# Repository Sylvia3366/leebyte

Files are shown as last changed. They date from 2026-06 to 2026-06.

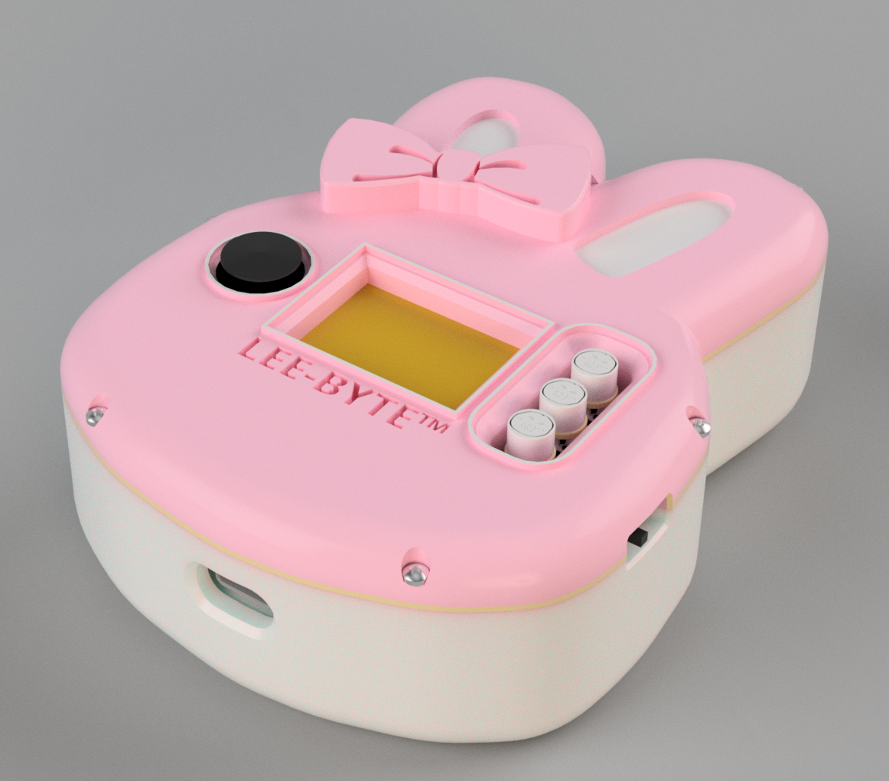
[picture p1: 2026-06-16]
images/leebyte_RENDER.png

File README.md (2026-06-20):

# LEEBYTE™
Copy of fallout_zine_template pdf-2

[ONSHAPE CAD](https://cad.onshape.com/documents/775b1919785149165ef0f27a/w/a0b05a09ec9f946b8b8a4a30/e/c002d06697f726d420ef8c8a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)
-

# What is it?
LEEBYTE is a mischevious tamagotchi pet bunny you can play with, take care of, bully, or put in your pocket and forget about for the next twenty years! It features a 2-axis joystick, three Jureumi themed buttons, and a temperature sensor that will cause LEEBYTE to have different reactions based on your enviornment :)!

# Why did I make it?
I made this project as a start point to my hardware journey! While starting with an odd, rabbit head PCB may not have been the best idea, it challenged me a lot. 

My main motivation after seeing the guide for it on Fallout website was the existing Leebit Tamagotchi [(See here!)](https://kplaceshop.com/products/stray-kids-skzoo-tamagotchi-case-set?variant=51409921999166). It's way out of my budget though, so I thought this would be the perfect chance for me to design one myself, and customize it to my own liking! Additionally, I've been wanting to get into pixel art for a while, and this project let me experiment with drawing so many different expressions and actions.

# How does it work?
LEEBYTE is unlike the usual 3-button tamagotchi pet; he can move! Using the joystick, you can take LEEBYTE on adventures and perhaps, you'll even find some cool treasures along the way... 

Like most tamagotchi, LEEBYTE also comes with 3 Jureumi themed buttons that can be pressed to feed him, play with him, or put him to sleep. Pressing two buttons at once can have some effect too :). When playing with LEEBYTE, he enjoys hula hooping, jump roping, or (if he's in the mood) you can even play a short game of some good ol' Tic-Tac-Toe. 

He's also able to detect the temperature of your enviornment. Make sure you keep him warm during the freezing winters and next to a blasting AC during the blazing summers! Otherwise, LEEBYTE might leave you...

# Designing the PCB
PCB designed on KiCad!
-
Screenshot 2026-06-15 at 11 00 14 PM
Screenshot 2026-06-15 at 11 01 25 PM
Screenshot 2026-06-15 at 11 01 33 PM
Screenshot 2026-06-14 at 1 18 59 AM

Case designed and assembled on OnShape!
-
Screenshot 2026-06-12 at 10 08 50 PM
Screenshot 2026-06-13 at 9 16 08 PM
Screenshot 2026-06-13 at 9 18 49 PM
Screenshot 2026-06-13 at 9 18 21 PM

Rendered on Fusion360!
-
Screenshot 2026-06-14 at 8 44 53 PM
leebyte_render

# Bill of Materials
| Name | Qty | Unit | Price (USD) | Total (USD) | MOQ | MOQ Price (USD) | Source |
| :--- | :---: | :---: | ---: | ---: | ---: | ---: | :--- |
| Seeed Studio XIAO ESP32 C3 | 1 | pcs | 11.14 | 11.14 | 1 | 11.14 | [Link](https://www.aliexpress.us/item/3256808047100037.html) |
| PSP 2-Axis Analog Thumb Joystick | 1 | pcs | 3.50 | 3.50 | 1 | 3.50 | [Link](https://www.adafruit.com/product/444) |
| 0.96 inch OLED Display 128x64 | 1 | pcs | 1.91 | 1.91 | 1 | 1.91 | [Link](https://www.aliexpress.us/item/2251832337475453.html) |
| Right Angle Slide Switch | 1 | pcs | 1.00 | 1.00 | 1 | 1.00 | [Link](https://www.alibaba.com/product-detail/Brand-New-Original-MST-12D18G4-SPDT_1601682630920.html) |
| 4.7k Resistor | 1 | pcs | 0.01 | 0.01 | 100 | 1.47 | [Link](https://www.aliexpress.us/item/2251832130817202.html) |
| Temperature Sensor (DS18B20) | 1 | pcs | 0.48 | 0.48 | 5 | 2.42 | [Link](https://www.aliexpress.us/item/3256808767131467.html) |
| Piezo Buzzer | 1 | pcs | 0.50 | 0.50 | 10 | 5.02 | [Link](https://www.aliexpress.us/item/3256810135642750.html) |
| Tactile Switch | 3 | pcs | 0.23 | 0.68 | 10 | 2.25 | [Link](https://www.aliexpress.us/item/3256807067168626.html) |
| M1.6 5mm Screws | 7 | pcs | 0.03 | 0.21 | 50 | 1.56 | [Link](https://www.aliexpress.us/item/2251832785290389.html) |
| M3 8mm Screws | 3 | pcs | 0.04 | 0.13 | 50 | 2.09 | [Link](https://www.aliexpress.us/item/2251832785290389.html) |
| M2 5mm Standoff | 2 | pcs | 0.15 | 0.30 | 20 | 2.94 | [Link](https://www.aliexpress.us/item/3256804631738035.html) |
| M2 Hex Nut | 2 | pcs | 0.07 | 0.14 | 50 | 3.38 | [Link](https://www.aliexpress.us/item/3256806284464354.html) |
| Battery | 1 | pcs | 5.16 | 5.16 | 1 | 5.16 | [Link](https://www.aliexpress.us/item/3256808658204287.html) |
| PCB | 1 | pcs | 0.40 | 0.40 | 5 | 2.00 | [Link](https://jlcpcb.com) |
| PLA 3D Printed Case | 1 | pcs | - | - | - | - | - |
| **Total** | **27** | **-** | **-** | **25.56** | **-** | **45.84** | **-** |

# Build & Assembly
Required Tools
-
1. Solder
2. Soldering iron
3. Tweezers
4. Screwdriver for M3/M2/M1.6 screws
5. Computer w. a USB port
6. 3D printer

Assembly
-
1. Solder all parts onto the PCB.
2. Secure the button caps onto the tact switches.
3. Secure the joystick with 2 M2 5mm screws, M2 standoffs, and M2 hex nuts.
4. Place the battery in the open part below the bottom case.
5. Place PCB into the bottom case and wire to battery.
6. Secure the PCB with 3 M3 screws.
7. Place the top case over the bottom and secure with the M1.6 screws.
8. Use Arduino IDE for the firmware.
9. Connect the ESP32 to your computer via USB-C to upload code.
10. Upload firmware.
11. Test the OLED display and test the joystick inputs.

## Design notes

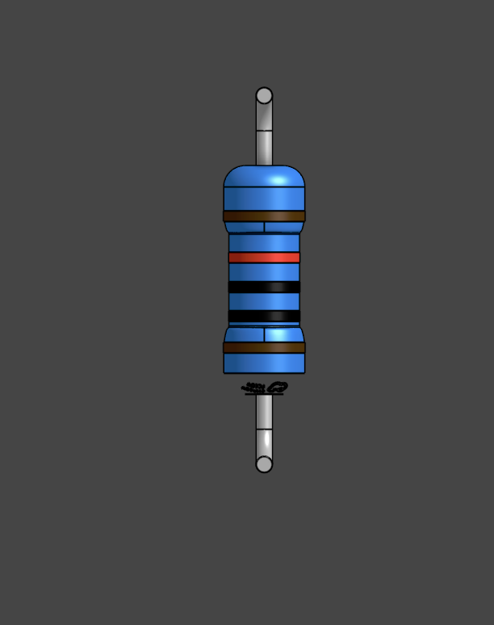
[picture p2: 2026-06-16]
case/CAD/4.7k Resistor Model/Resistor.png

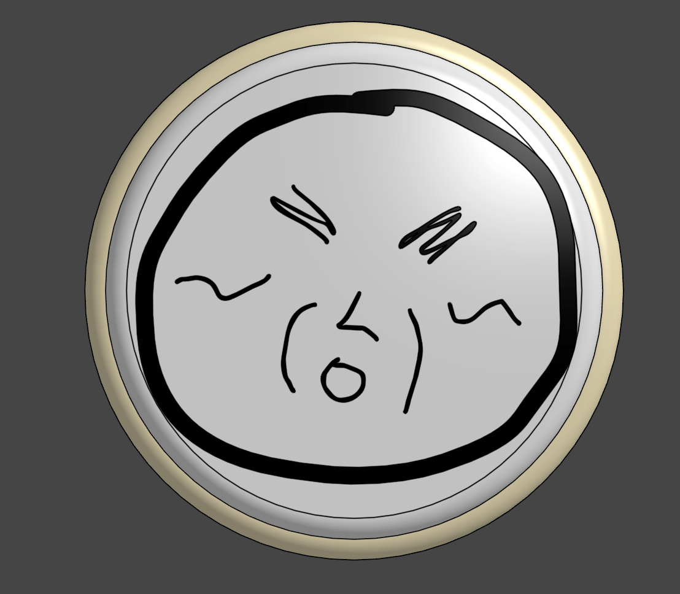
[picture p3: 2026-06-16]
case/Button Cap Model/Button.png

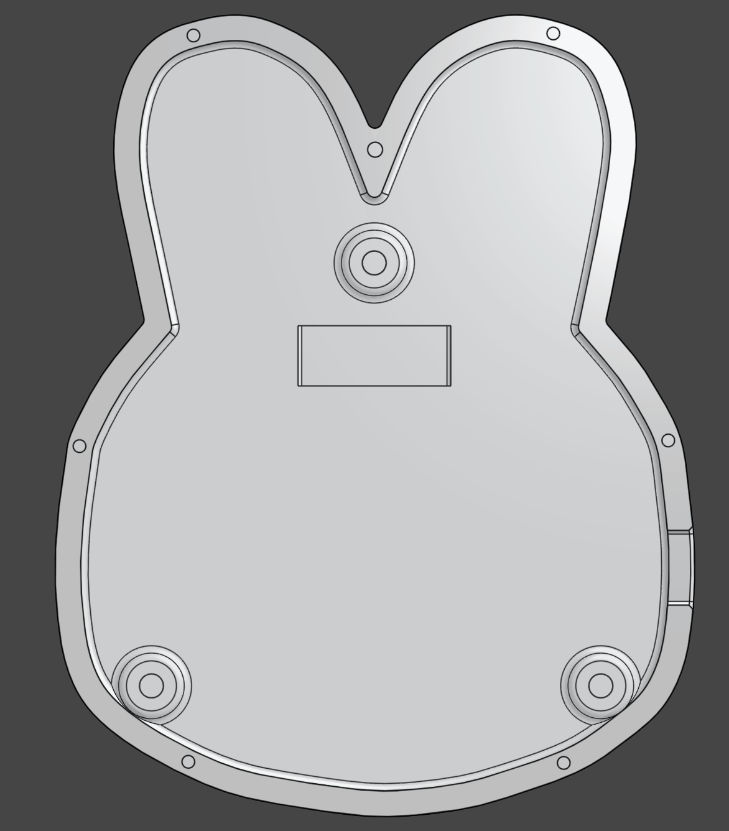
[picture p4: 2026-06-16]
case/Bottom Case Model/Btm_case.png

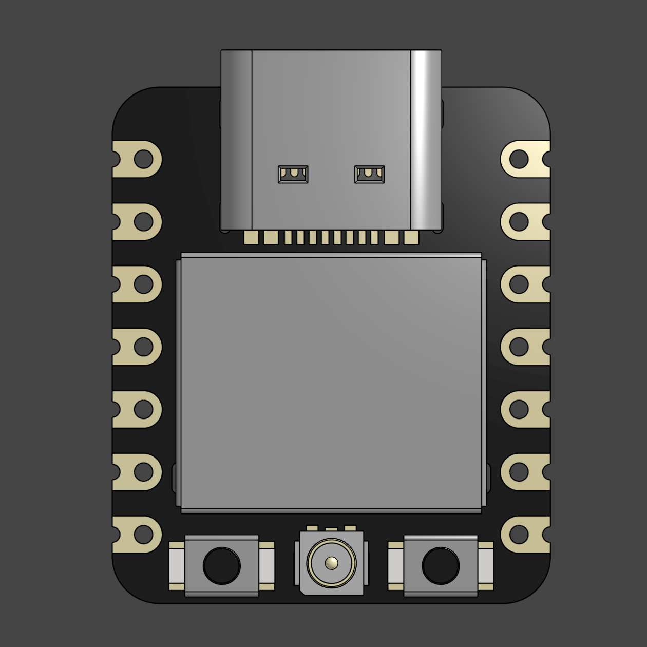
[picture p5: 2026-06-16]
case/CAD/Seeed Studio XIAO ESP32 C3 Model/seeed1.png

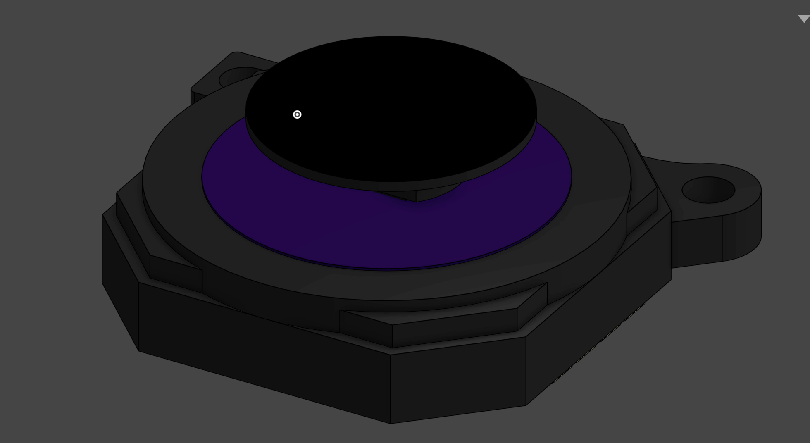
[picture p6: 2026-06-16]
case/CAD/2-axis Analog Thumb Joystick Model/Joystick.png

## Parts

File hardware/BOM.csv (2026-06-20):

Name | Qty | Unit | Price (USD) | Total (USD) | MOQ | MOQ Price (USD) | Source
Seeed Studio XIAO ESP32 C3 | 1 | pcs | 11.14 | 11.14 | 1 | 11.14 | https://www.aliexpress.us/item/3256808047100037.html
PSP 2-Axis Analog Thumb Joystick | 1 | pcs | 3.50 | 3.50 | 1 | 3.50 | https://www.adafruit.com/product/444
0.96 inch OLED Display 128x64 | 1 | pcs | 1.91 | 1.91 | 1 | 1.91 | https://www.aliexpress.us/item/2251832337475453.html
Right Angle Slide Switch | 1 | pcs | 1.00 | 1.00 | 1 | 1.00 | https://www.alibaba.com/product-detail/Brand-New-Original-MST-12D18G4-SPDT_1601682630920.html
4.7k Resistor | 1 | pcs | 0.01 | 0.01 | 100 | 1.47 | https://www.aliexpress.us/item/2251832130817202.html
Temperature Sensor (DS18B20) | 1 | pcs | 0.48 | 0.48 | 5 | 2.42 | https://www.aliexpress.us/item/3256808767131467.html
Piezo Buzzer | 1 | pcs | 0.50 | 0.50 | 10 | 5.02 | https://www.aliexpress.us/item/3256810135642750.html
Tactile Switch | 3 | pcs | 0.23 | 0.68 | 10 | 2.25 | https://www.aliexpress.us/item/3256807067168626.html
M1.6 5mm Screws | 7 | pcs | 0.03 | 0.21 | 50 | 1.56 | https://www.aliexpress.us/item/2251832785290389.html
M3 8mm Screws | 3 | pcs | 0.04 | 0.13 | 50 | 2.09 | https://www.aliexpress.us/item/2251832785290389.html
M2 5mm Standoff | 2 | pcs | 0.15 | 0.30 | 20 | 2.94 | https://www.aliexpress.us/item/3256804631738035.html
M2 Hex Nut | 2 | pcs | 0.07 | 0.14 | 50 | 3.38 | https://www.aliexpress.us/item/3256806284464354.html
Battery | 1 | pcs | 5.16 | 5.16 | 1 | 5.16 | https://www.aliexpress.us/item/3256808658204287.html
PLA 3D Printed Case | 1 | pcs | - | - | - | - | -
PCB | 1 | pcs | 0.40 | 0.40 | 5 | 2.00 | https://jlcpcb.com
Total | 27 | - | - | 25.56 | - | 45.84 | -

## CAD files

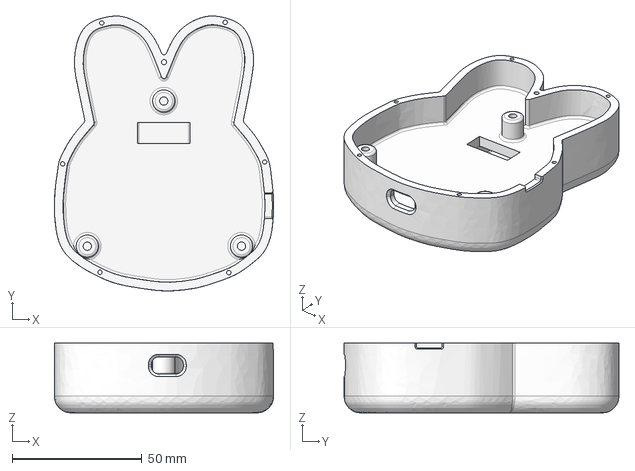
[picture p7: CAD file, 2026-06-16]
case/Bottom Case Model/Bottom_case.step
84.7 x 106.1 x 27.0 mm

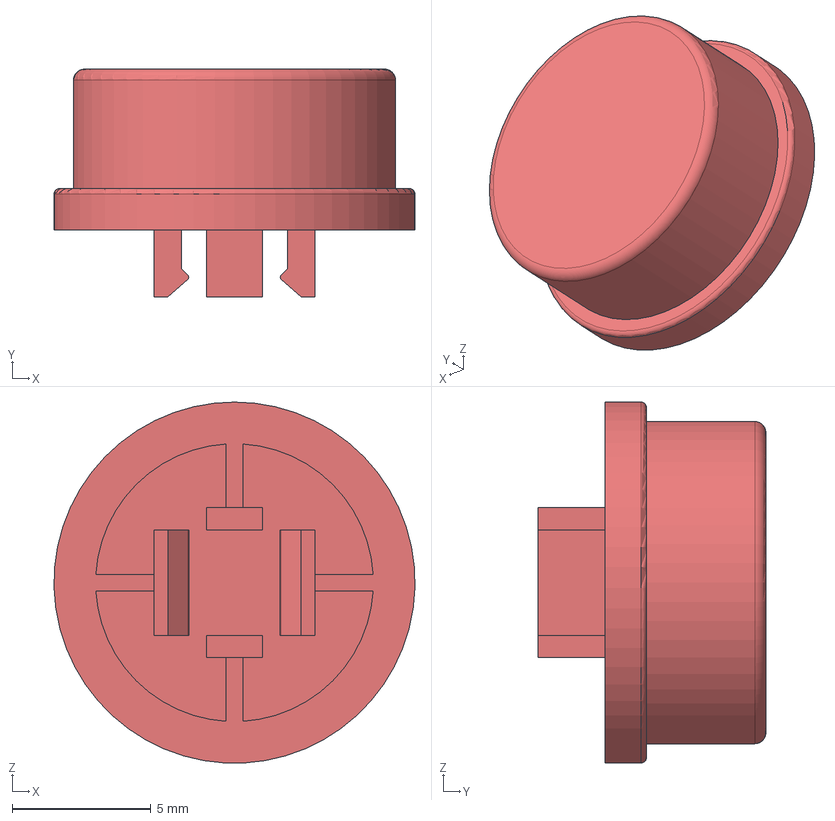
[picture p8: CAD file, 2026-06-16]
case/Button Cap Model/12mm Push Button Cap (REFERENCE).step
13.0 x 8.20 x 13.0 mm

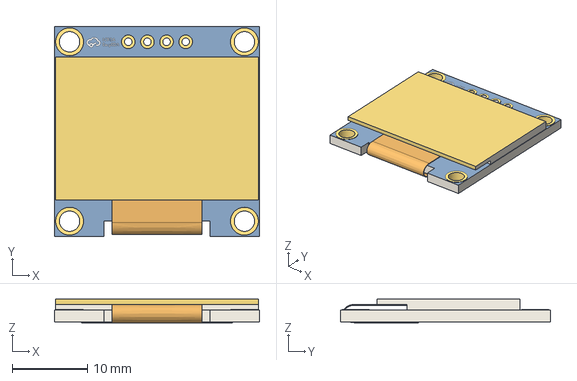
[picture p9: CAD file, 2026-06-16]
case/CAD/128x64 OLED Model/OLED-TH_L27.8-W27.2-P2.54_C9900033791 (1).step
27.2 x 27.8 x 3.12 mm

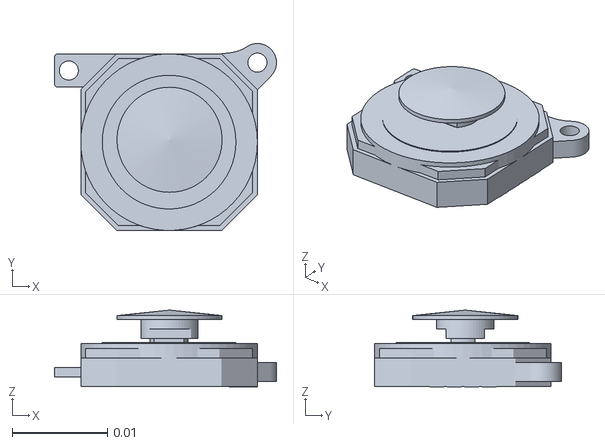
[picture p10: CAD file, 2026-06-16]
case/CAD/2-axis Analog Thumb Joystick Model/PspJoystick v5.stl
0.0232 x 0.0196 x 0.00805

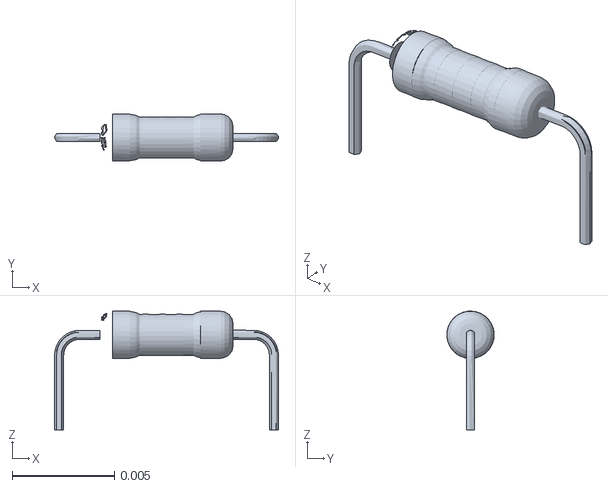
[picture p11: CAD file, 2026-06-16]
case/CAD/4.7k Resistor Model/RES-TH_D2.3-L6.5-P10.50 (2).stl
0.0109 x 0.00232 x 0.00581

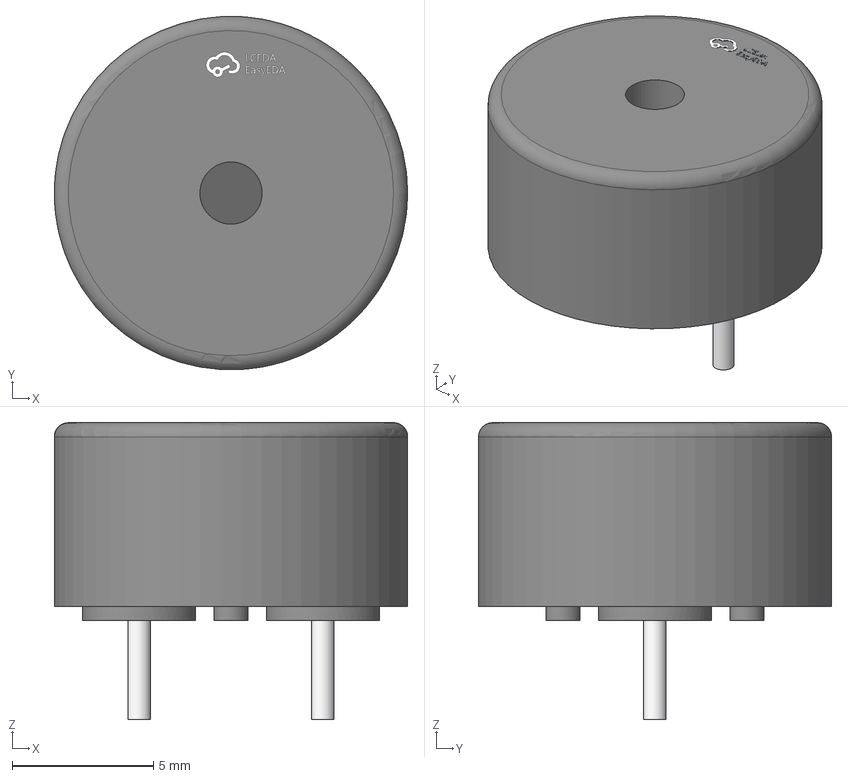
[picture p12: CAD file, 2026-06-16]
case/CAD/Buzzer Model/BUZ-TH_BD12.5-H7.0-P6.5 (1).step
12.5 x 12.5 x 10.5 mm

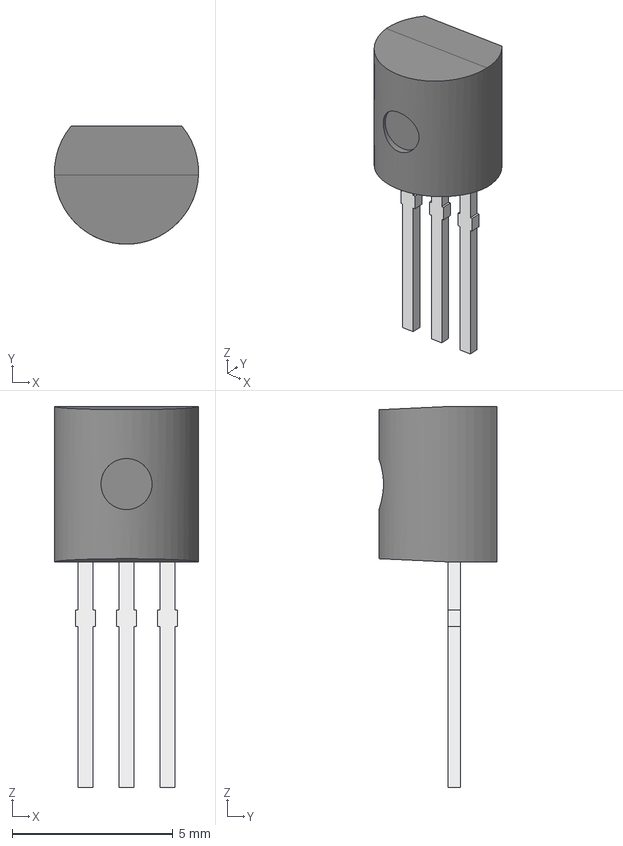
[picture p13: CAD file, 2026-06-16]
case/CAD/DS18B20 Model/Áã¼þ11 (1).step
4.48 x 3.68 x 11.8 mm

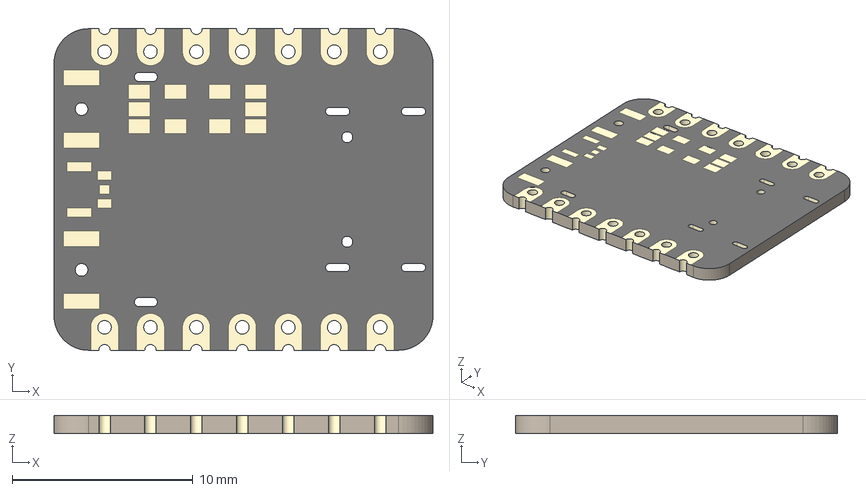
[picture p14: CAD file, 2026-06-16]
case/CAD/Seeed Studio XIAO ESP32 C3 Model/Seeed Studio XIAO-ESP32-C3 - Seeed Studio XIAO-ESP32-C3 v15.step
21.0 x 17.8 x 1 mm

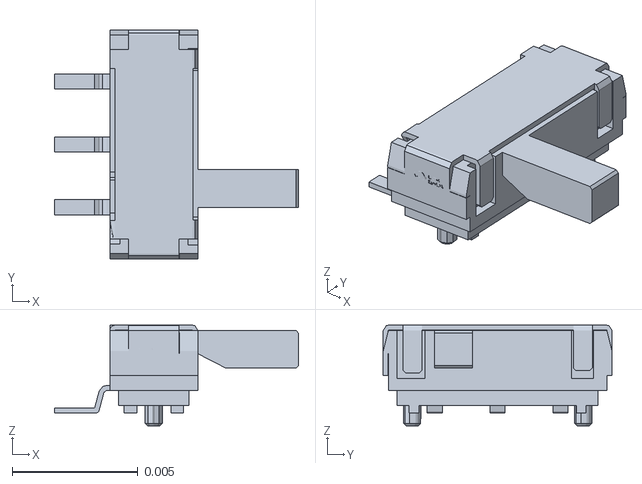
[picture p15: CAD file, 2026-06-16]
case/CAD/Slide Switch Model/tamagotchipcb123 1.stl
0.0097 x 0.00911 x 0.004

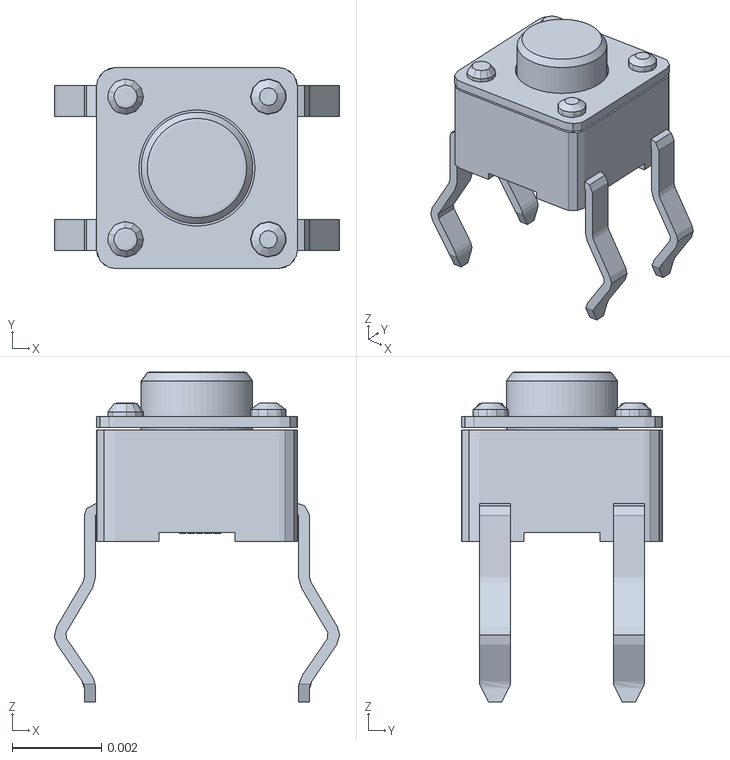
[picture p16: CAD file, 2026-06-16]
case/CAD/Tact Switch Model/SW-TH_4P-L4.5-W4.5-P3.00-LS4.8.stl
0.0064 x 0.0045 x 0.0074

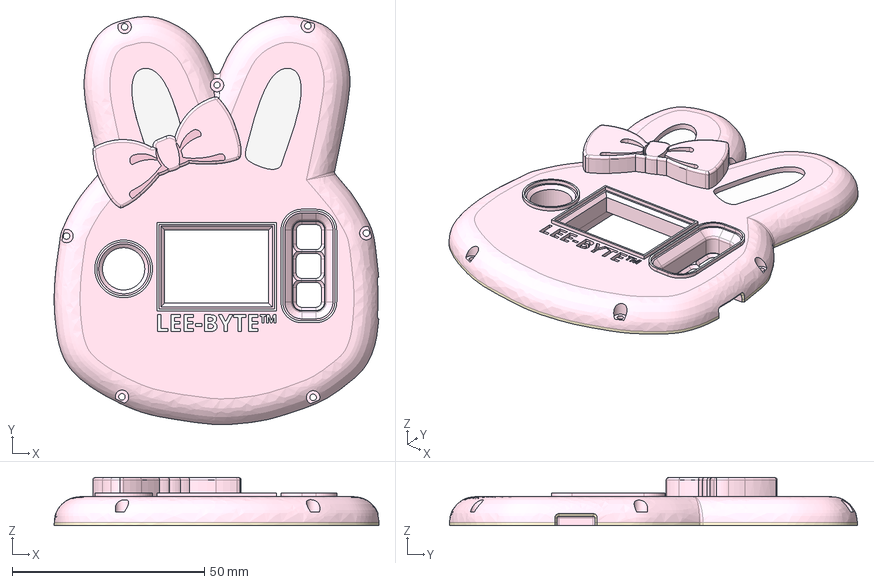
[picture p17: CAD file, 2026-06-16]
case/Top Case Model/Top_case.step
84.4 x 106.1 x 12.5 mm

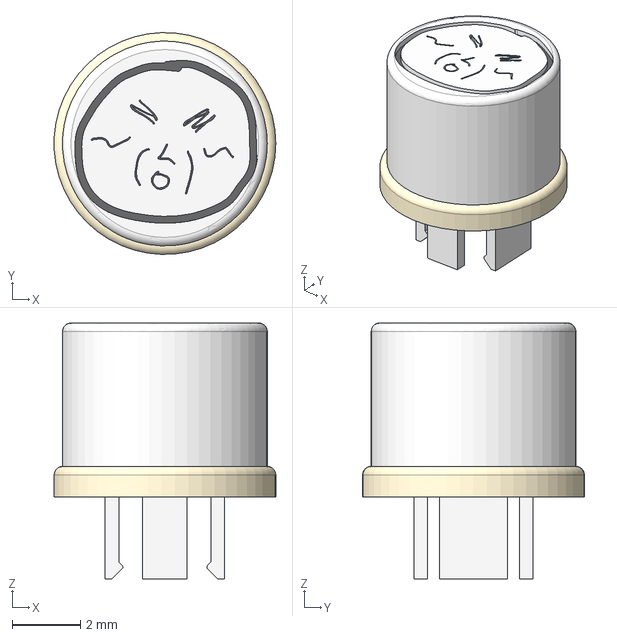
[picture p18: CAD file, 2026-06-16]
case/Button Cap Model/Button_cap.step
6.49 x 6.50 x 7.50 mm

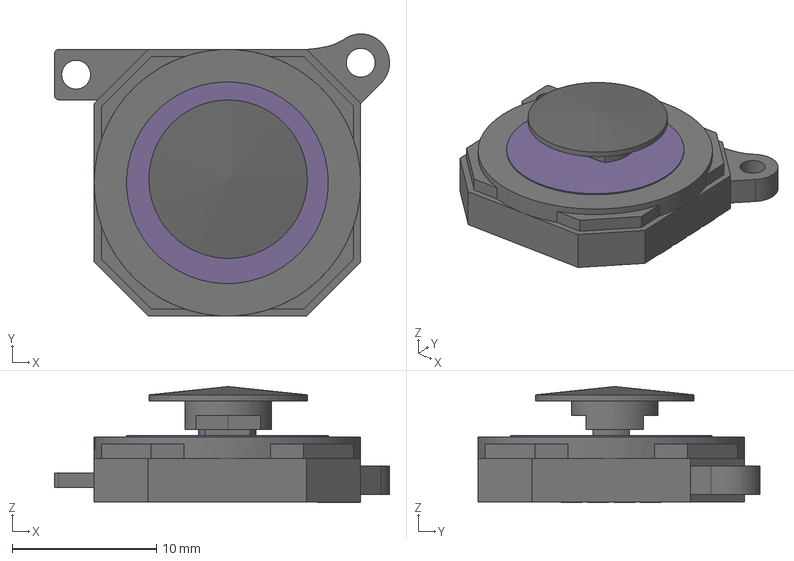
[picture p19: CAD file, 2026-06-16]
case/CAD/2-axis Analog Thumb Joystick Model/PspJoystick v5-2.step
23.2 x 19.6 x 8.05 mm
PspJoystick v6 x 7

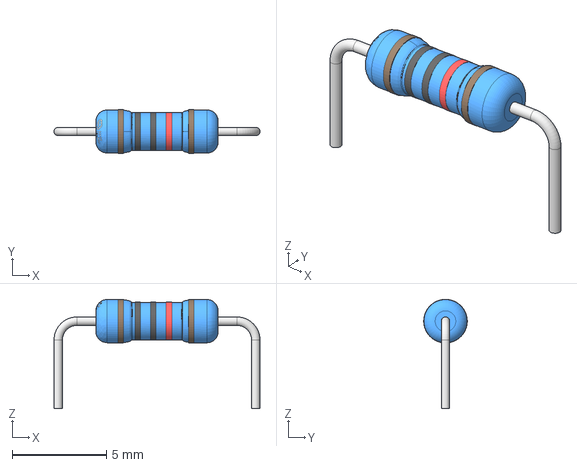
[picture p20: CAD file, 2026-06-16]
case/CAD/4.7k Resistor Model/RES-TH_D2.3-L6.5-P10.50 (1).step
10.9 x 2.32 x 5.81 mm

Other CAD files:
case/CAD/Slide Switch Model/Slide Switch.step
case/CAD/Tact Switch Model/SW-TH_4P-L4.5-W4.5-P3.00-LS4.8 (1).step
case/CAD/M1.6x0.35mm 6mm Screw Model/PZ Pan head screw M1.6x0.35 x 6.stl
case/CAD/M2 4mm Standoff Model/M2 x 5 across flats 4mm.step
case/Bottom Case Model/Bottom_case.stl
case/Button Cap Model/12mm Push Button Cap (REFERENCE).stl
case/Button Cap Model/Button_cap.stl
case/CAD/128x64 OLED Model/OLED-TH_L27.8-W27.2-P2.54_C9900033791 (1).stl
case/CAD/Buzzer Model/BUZ-TH_BD12.5-H7.0-P6.5 (1).stl
case/CAD/DS18B20 Model/Áã¼þ11 (1).stl
case/CAD/M1.6x0.35mm 6mm Screw Model/tamagotchipcb123 1 - PZ Pan head screw M1.6x0.35 x 8.step
case/CAD/M2 4mm Standoff Model/M2 x 5 across flats 4mm.stl
case/CAD/M2 Hexnut Model/Hex nut style 1 grade A & B M2x0.4.step
case/CAD/M2 Hexnut Model/Hex nut style 1 grade A & B M2x0.4.stl
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

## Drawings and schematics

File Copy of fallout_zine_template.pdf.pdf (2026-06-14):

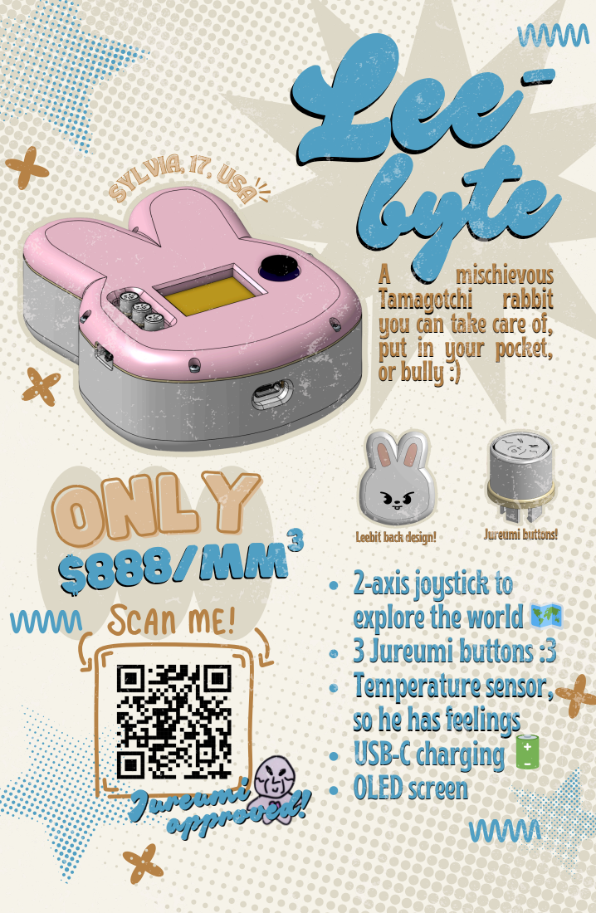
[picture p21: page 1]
Lee- byte; onlyy $888/mm; 2-axis joystickto; OLED screen; SYLVIA, 17, USA; Leebitbackdesign!; Jureumibuttons!

A mischievous
Tamagotchi rabbit
you can take care of,
put in your pocket,
orbully:)

2-axis joystickto
explore the world️
explore the world🗺
3 Jureumibuttons :3
Temperature sensor,
so he has feelings
USB-C charging🔋
OLED screen

Jureumi Jureumi Jureumi

approved! approved! approved!

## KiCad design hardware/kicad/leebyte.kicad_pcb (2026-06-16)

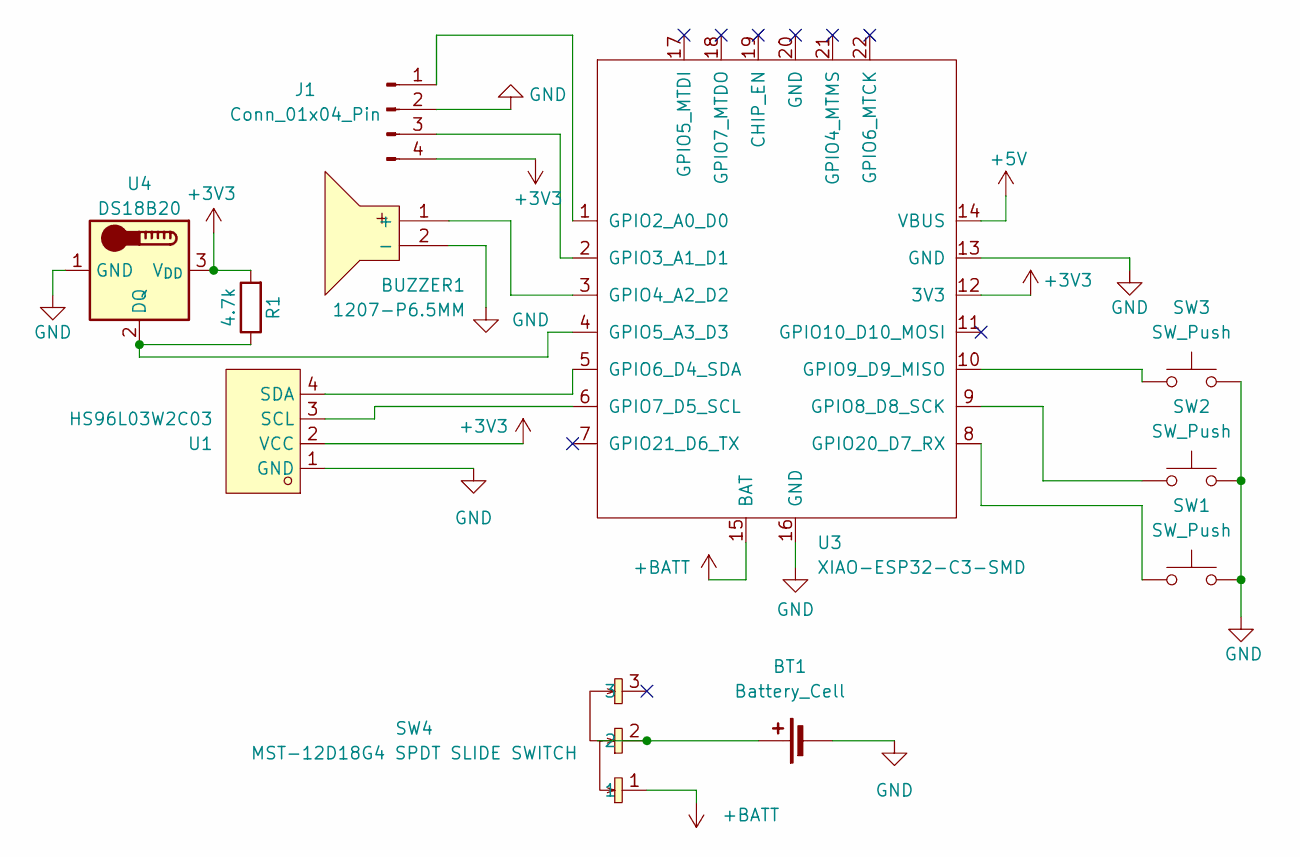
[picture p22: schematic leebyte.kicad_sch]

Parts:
BT1: Battery_Cell; PinHeader_1x02_P2.54mm_Vertical
BUZZER1: 1207-P6.5MM; BUZ-TH_BD12.5-P6.50-D1.4; MPN 1207-P6.5MM; LCSC Part C49246964
J1: Conn_01x04_Pin; JOYSTICK-PSP1000
R1: 4.7k; RES-TH_BD2.3-L6.5-P10.50-D0.5
SW1, SW2, SW3: SW_Push; SW-TH_4P-L4.5-W4.5-P3.00-LS4.8
SW4: MST-12D18G4 SPDT SLIDE SWITCH; SW-SMD_MST-12D18G4-SPDT-SLIDE-SWITCH; MPN MST-12D18G4 SPDT Slide Switch; LCSC Part C49023767
U1: HS96L03W2C03; OLED-TH_L27.8-W27.2-P2.54_C9900033791; MPN HS96L03W2C03; LCSC Part C5248080
U3: XIAO-ESP32-C3-SMD; XIAO-ESP32-C3-DIP-SMD
U4: DS18B20; TO-92-3_L4.9-W3.7-P1.27-L

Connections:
+3V3: J1.4, R1.2, U1.2 (VCC), U3.12 (3V3), U4.3 (V_{DD})
+5V: U3.14 (VBUS)
+BATT: SW4.1, U3.15 (BAT)
GND: BT1.2 (-), BUZZER1.2 (-), J1.2, SW1.2, SW2.2, SW3.2, U1.1 (GND), U3.13 (GND), U3.16 (GND), U4.1 (GND)
unnamed: BT1.1 (+), SW4.2
unnamed: BUZZER1.1 (+), U3.3 (GPIO4_A2_D2)
unnamed: J1.1, U3.1 (GPIO2_A0_D0)
unnamed: J1.3, U3.2 (GPIO3_A1_D1)
unnamed: U1.3 (SCL), U3.6 (GPIO7_D5_SCL)
unnamed: U1.4 (SDA), U3.5 (GPIO6_D4_SDA)
unnamed: R1.1, U3.4 (GPIO5_A3_D3), U4.2 (DQ)
unnamed: SW2.1, U3.9 (GPIO8_D8_SCK)
unnamed: SW3.1, U3.10 (GPIO9_D9_MISO)
unnamed: SW1.1, U3.8 (GPIO20_D7_RX)

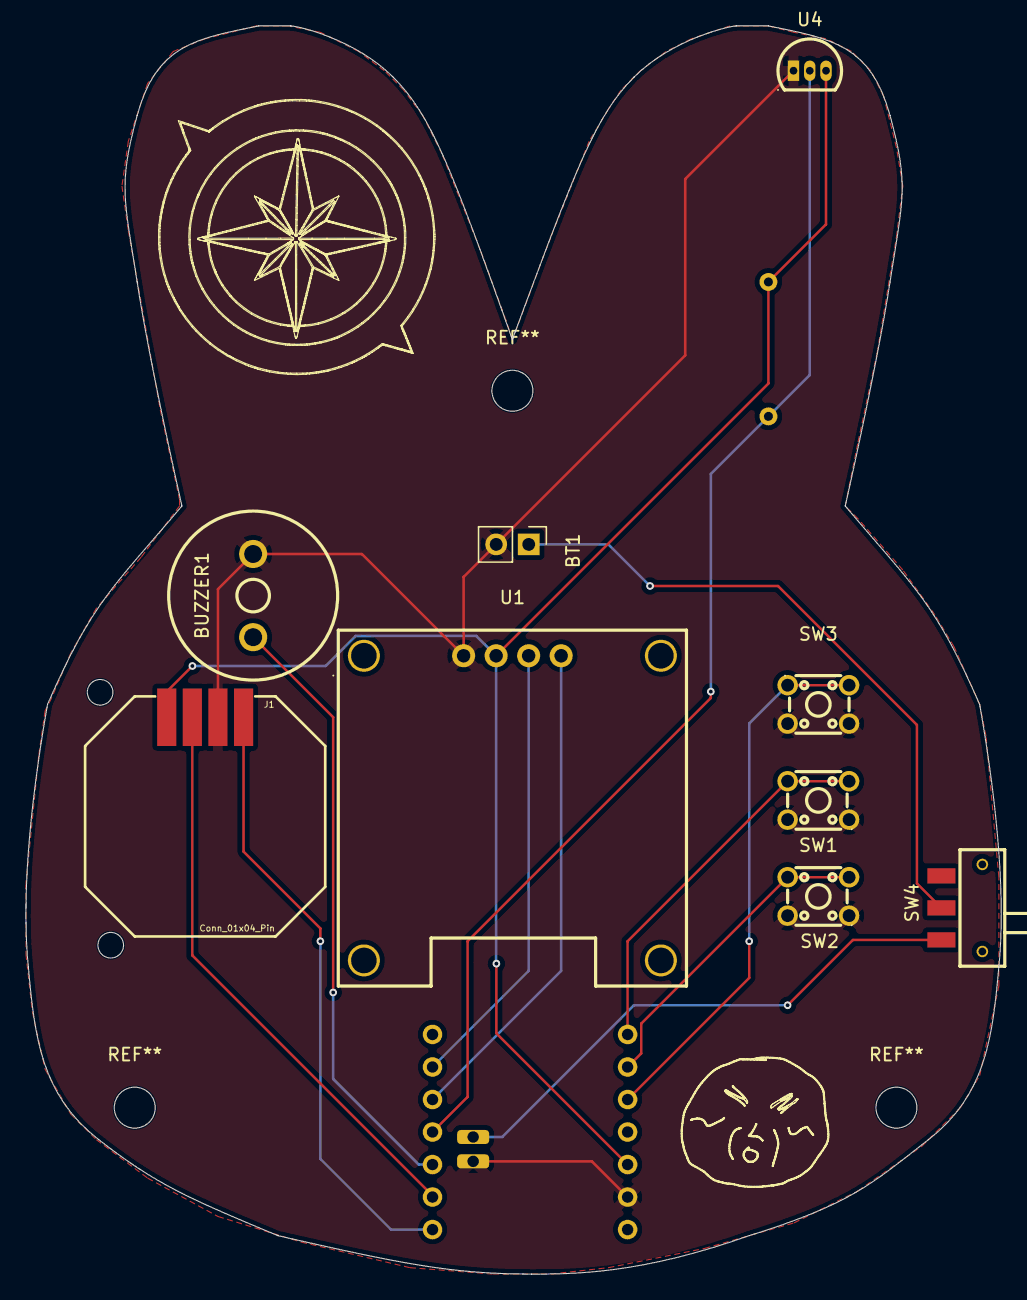
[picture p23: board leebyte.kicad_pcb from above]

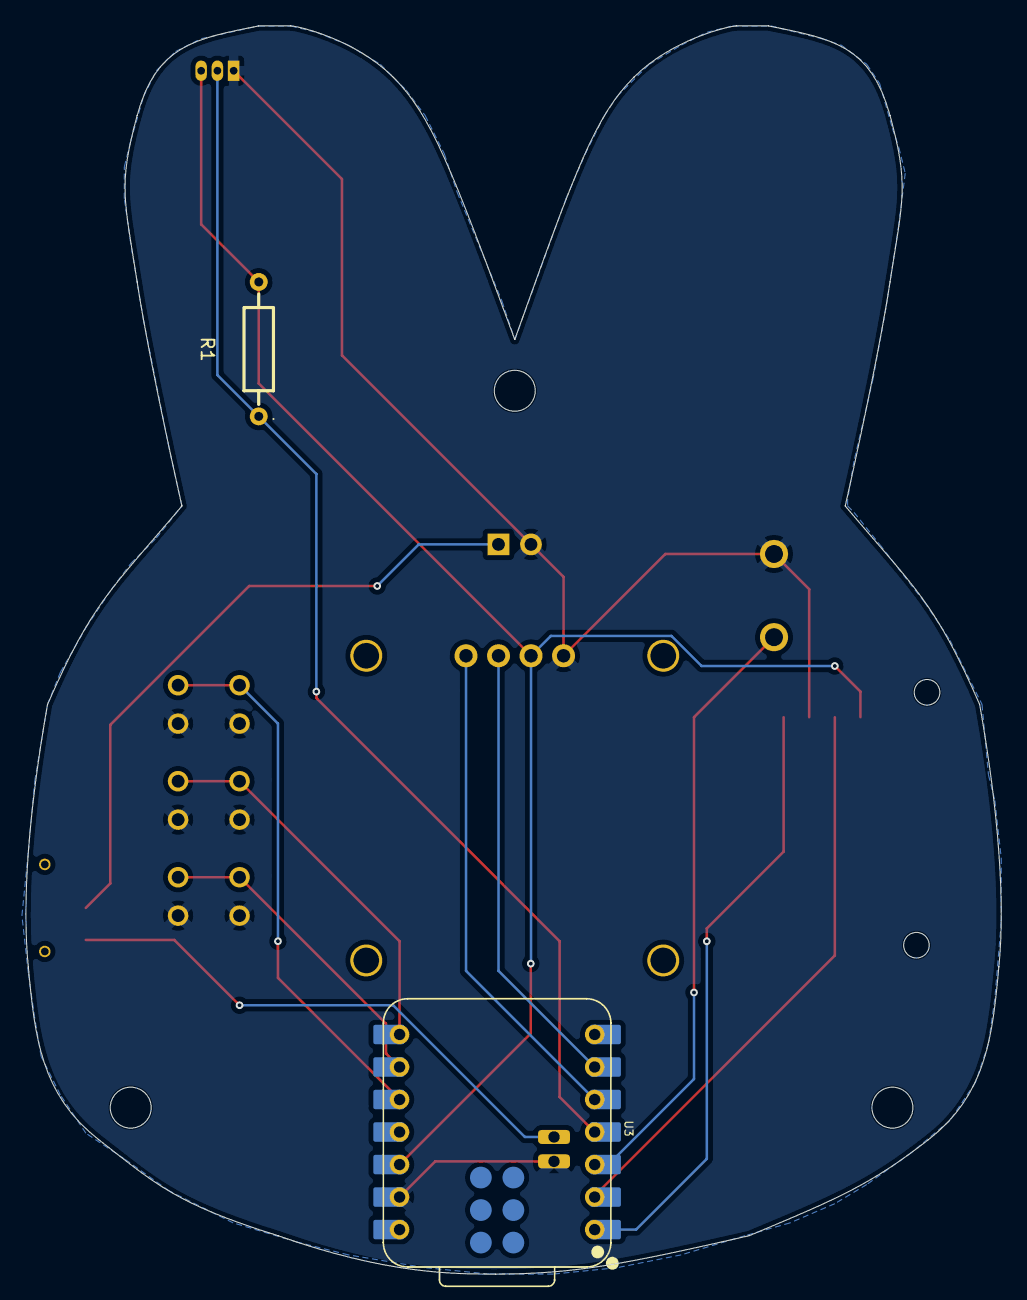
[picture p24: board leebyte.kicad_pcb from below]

Board: 2 copper layers, 76.2 x 97.5 mm, 11 parts (2 on the bottom side), 13 nets.

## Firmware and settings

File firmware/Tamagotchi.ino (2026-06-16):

//------------LIBS------------
#include <Wire.h>
#include <Adafruit_GFX.h>
#include <Adafruit_SSD1306.h>
#include <OneWire.h>
#include <DallasTemperature.h>

//------------DEFINE GIPO------------
#define BTN1 20
#define BTN2 8
#define BTN3 9
#define SDA_PIN 6
#define SCL_PIN 7
#define BUZZER 4
#define TEMP 5
#define LEFT_RIGHT 2
#define UP_DOWN 3

//------------CONFIGURE HARDWARE------------
#define SCREEN_WIDTH 128
#define SCREEN_HEIGHT 64
#define OLED_RESET -1
Adafruit_SSD1306 display(SCREEN_WIDTH, SCREEN_HEIGHT, &Wire, OLED_RESET);

#define TEMP_PIN D3
OneWire oneWire(TEMP_PIN);
DallasTemperature sensors(&oneWire);

#define BTN_TOP D9
#define BTN_MIDDLE D8
#define BTN_BOTTOM D7

#define BUZZER_PIN D2

#define X_PIN D0
#define Y_PIN D1

//------------CREATE PET------------
struct Pet {
  int hunger;
  int happiness;
  int energy;
  unsigned long age;
};

Pet pet;

//------------PET ANIMATIONS------------
const unsigned char PROGMEM petNeutral[] = {
  0b00000000, 0b00000000, 0b00000000, 0b00000000,
  0b00000000, 0b11100000, 0b00000111, 0b00000000,
  0b00000001, 0b00010000, 0b00001000, 0b10000000,
  0b00000010, 0b00010000, 0b00001000, 0b01000000,
  0b00000100, 0b11001000, 0b00010011, 0b00100000,
  0b00000100, 0b11001000, 0b00010011, 0b00100000,
  0b00000100, 0b11100100, 0b00100111, 0b00100000,
  0b00000010, 0b01110010, 0b01001110, 0b01000000,
  0b00000001, 0b01111010, 0b01011110, 0b10000000,
  0b00000001, 0b00011001, 0b10011000, 0b10000000,
  0b00000010, 0b00000000, 0b00000000, 0b01000000,
  0b00000100, 0b00000000, 0b00000000, 0b00100000,
  0b00000100, 0b00000000, 0b00000000, 0b00100000,
  0b00000100, 0b00011000, 0b00011000, 0b00100000,
  0b00001000, 0b00011000, 0b00011000, 0b00010000,
  0b00001000, 0b00011000, 0b00011000, 0b00010000,
  0b00001000, 0b00000001, 0b10000000, 0b00010000,
  0b00001000, 0b00000000, 0b00000000, 0b00010000,
  0b00001000, 0b00000000, 0b00000000, 0b00010000,
  0b00001000, 0b00001111, 0b11110000, 0b00010000,
  0b00000100, 0b00000010, 0b01000000, 0b00100000,
  0b00000100, 0b00000011, 0b11000000, 0b00100000,
  0b00000011, 0b00000000, 0b00000000, 0b11000000,
  0b00000010, 0b00000000, 0b00000000, 0b01000000,
  0b00000100, 0b00000000, 0b00000000, 0b00100000,
  0b00000100, 0b01000000, 0b00000010, 0b00100000,
  0b00000010, 0b01000000, 0b00000010, 0b01000000,
  0b00000001, 0b11000000, 0b00000011, 0b10000000,
  0b00000000, 0b01000000, 0b00000010, 0b00000000,
  0b00000000, 0b01000000, 0b00000010, 0b00000000,
  0b00000000, 0b01000001, 0b10000010, 0b00000000,
  0b00000000, 0b00111110, 0b01111100, 0b00000000
};
const unsigned char PROGMEM petHappy[] = {
  0b00000000, 0b00000000, 0b00000000, 0b00000000,
  0b00000000, 0b11100000, 0b00000111, 0b00000000,
  0b00000001, 0b00010000, 0b00001000, 0b10000000,
  0b00000010, 0b00010000, 0b00001000, 0b01000000,
  0b00000100, 0b11001000, 0b00010011, 0b00100000,
  0b00000100, 0b11001000, 0b00010011, 0b00100000,
  0b00000100, 0b11100100, 0b00100111, 0b00100000,
  0b00000010, 0b01110010, 0b01001110, 0b01001010,
  0b00000001, 0b01111010, 0b01011110, 0b10011111,
  0b01010001, 0b00011001, 0b10011000, 0b10001110,
  0b01110010, 0b00000000, 0b00000000, 0b01000100,
  0b00100100, 0b00000000, 0b00000000, 0b00100000,
  0b00000100, 0b00000000, 0b00000000, 0b00100000,
  0b00000100, 0b00110000, 0b00001100, 0b00100000,
  0b00001000, 0b00001000, 0b00010000, 0b00010000,
  0b00001000, 0b00000100, 0b00100000, 0b00010000,
  0b00001000, 0b00111001, 0b10011100, 0b00010000,
  0b00001000, 0b00000000, 0b00000000, 0b00010000,
  0b00001001, 0b10001001, 0b10010001, 0b10010000,
  0b00001001, 0b10000110, 0b01100001, 0b10010000,
  0b00000100, 0b00000100, 0b00100000, 0b00100000,
  0b00000100, 0b00000010, 0b01000000, 0b00100000,
  0b00000011, 0b00000001, 0b10000000, 0b11000000,
  0b00000010, 0b00000000, 0b00000000, 0b01000000,
  0b00000100, 0b00000000, 0b00000000, 0b00100000,
  0b00000100, 0b01000000, 0b00000010, 0b00100000,
  0b00000010, 0b01000000, 0b00000010, 0b01000000,
  0b00000001, 0b11000000, 0b00000011, 0b10000000,
  0b00000000, 0b01000000, 0b00000010, 0b00000000,
  0b00000000, 0b01000000, 0b00000010, 0b00000000,
  0b00000000, 0b01000001, 0b10000010, 0b00000000,
  0b00000000, 0b00111110, 0b01111100, 0b00000000
};
const unsigned char PROGMEM petSad[] = {
  0b00000000, 0b00000000, 0b00000000, 0b00000000,
  0b00000000, 0b11100000, 0b00000111, 0b00000000,
  0b00000001, 0b00010000, 0b00001000, 0b10000000,
  0b00000010, 0b00010000, 0b00001000, 0b01000000,
  0b00000100, 0b00001000, 0b00010000, 0b00100000,
  0b00001000, 0b00001000, 0b00010000, 0b00010000,
  0b00010000, 0b00000100, 0b00100000, 0b00011000,
  0b00110000, 0b00010010, 0b01001000, 0b00001100,
  0b00100000, 0b00111010, 0b01011100, 0b00000100,
  0b00110000, 0b01111001, 0b10011110, 0b00001100,
  0b00011100, 0b11000000, 0b00000011, 0b00111000,
  0b00000111, 0b10000000, 0b00000001, 0b11100000,
  0b00000100, 0b00000000, 0b00000000, 0b00100000,
  0b00000100, 0b01100000, 0b00000110, 0b00100000,
  0b00001000, 0b00011000, 0b00011000, 0b00010000,
  0b00001000, 0b00000100, 0b00100000, 0b00010000,
  0b00001000, 0b01111001, 0b10011110, 0b00010000,
  0b00001000, 0b00000000, 0b00000000, 0b00010000,
  0b00001000, 0b01000000, 0b00000010, 0b00010000,
  0b00001000, 0b00001111, 0b11110000, 0b00010000,
  0b00000100, 0b01010010, 0b01001010, 0b00100000,
  0b00000100, 0b00000011, 0b11000000, 0b00100000,
  0b00000011, 0b00000000, 0b00000000, 0b11000000,
  0b00000010, 0b00000000, 0b00000000, 0b01000000,
  0b00000100, 0b00000000, 0b00000000, 0b00100000,
  0b00000100, 0b01000000, 0b00000010, 0b00100000,
  0b00000010, 0b01000000, 0b00000010, 0b01000000,
  0b00000001, 0b11000000, 0b00000011, 0b10000000,
  0b00000000, 0b01000000, 0b00000010, 0b00000000,
  0b00000000, 0b01000000, 0b00000010, 0b00000000,
  0b00000000, 0b01000001, 0b10000010, 0b00000000,
  0b00000000, 0b00111110, 0b01111100, 0b00000000
};
const unsigned char PROGMEM petSleep[] = {
  0b00000000, 0b00000000, 0b11110000, 0b00000000,
  0b00000000, 0b11100011, 0b10001111, 0b00000000,
  0b00000001, 0b00010110, 0b00000001, 0b11000000,
  0b00000010, 0b00011100, 0b00000000, 0b01000000,
  0b00000100, 0b00001000, 0b00000000, 0b01110000,
  0b00001000, 0b00110000, 0b00000111, 0b11001000,
  0b00010000, 0b00100000, 0b00001000, 0b01001000,
  0b00110000, 0b11000000, 0b00011100, 0b01111100,
  0b00100001, 0b00111111, 0b11100110, 0b00000100,
  0b00110001, 0b00000000, 0b00000010, 0b00001100,
  0b00011101, 0b11110000, 0b00001110, 0b00111000,
  0b00000111, 0b10001111, 0b11111001, 0b11100000,
  0b00000100, 0b00000000, 0b00000000, 0b00100000,
  0b00000100, 0b01001000, 0b00010010, 0b00100000,
  0b00001000, 0b01001000, 0b00010010, 0b00010000,
  0b00001000, 0b01001000, 0b00010010, 0b00010000,
  0b00001000, 0b00110001, 0b10001100, 0b00010000,
  0b00001000, 0b00000000, 0b00000000, 0b00010000,
  0b00001000, 0b00000000, 0b00000000, 0b00010000,
  0b00001000, 0b00001111, 0b11110000, 0b00010000,
  0b00000100, 0b00000010, 0b01000000, 0b00100000,
  0b00000100, 0b00000011, 0b11000000, 0b00100000,
  0b00000011, 0b00000000, 0b00000000, 0b11000000,
  0b00000010, 0b00000000, 0b00000000, 0b01000000,
  0b00000100, 0b00000000, 0b00000000, 0b00100000,
  0b11110100, 0b01000000, 0b00000010, 0b00101111,
  0b00100010, 0b01000000, 0b00000010, 0b01000010,
  0b01000001, 0b11000000, 0b00000011, 0b10000100,
  0b11110000, 0b01000000, 0b00000010, 0b00001111,
  0b00000000, 0b01000000, 0b00000010, 0b00000000,
  0b00000000, 0b01000001, 0b10000010, 0b00000000,
  0b00000000, 0b00111110, 0b01111100, 0b00000000
};
const unsigned char PROGMEM petCold[] = {
  0b00000000, 0b00001000, 0b00000000, 0b00000000,
  0b01000000, 0b11100100, 0b00000111, 0b00000000,
  0b11110001, 0b00010100, 0b00001000, 0b10000000,
  0b01000010, 0b00010000, 0b00001000, 0b01000000,
  0b01000100, 0b00001000, 0b00010000, 0b00100000,
  0b00001000, 0b00001000, 0b00010000, 0b00010000,
  0b00010000, 0b00000100, 0b00100000, 0b00011000,
  0b00110000, 0b00010010, 0b01001000, 0b00001100,
  0b00100000, 0b00111010, 0b01011100, 0b00000100,
  0b00110000, 0b01111001, 0b10011110, 0b00001100,
  0b00011100, 0b11000000, 0b00000011, 0b00111000,
  0b00000111, 0b10000000, 0b00000001, 0b11100000,
  0b00000100, 0b00000000, 0b00000000, 0b00100000,
  0b00000100, 0b00111000, 0b00011100, 0b00100000,
  0b00001000, 0b00101000, 0b00010100, 0b00010000,
  0b00001000, 0b00111000, 0b00011100, 0b00010000,
  0b00001000, 0b00000001, 0b10000000, 0b00010000,
  0b00001000, 0b00000000, 0b00000000, 0b00010000,
  0b00101000, 0b00000000, 0b00000000, 0b00010000,
  0b00101000, 0b00001111, 0b11110000, 0b00010000,
  0b00110100, 0b00010010, 0b01001000, 0b00100100,
  0b00010100, 0b00000011, 0b11000000, 0b00101100,
  0b00001011, 0b00000000, 0b00000000, 0b11011000,
  0b00000010, 0b00000000, 0b00000000, 0b01000000,
  0b00000100, 0b00000000, 0b00000000, 0b00100000,
  0b00000100, 0b01000000, 0b00000010, 0b00100000,
  0b00000010, 0b01000000, 0b00000010, 0b01000010,
  0b00100001, 0b11000000, 0b00000011, 0b10000111,
  0b01110000, 0b01000000, 0b00000010, 0b00000010,
  0b11111000, 0b01000000, 0b00000010, 0b00000000,
  0b01110000, 0b01000001, 0b10000010, 0b00000000,
  0b00100000, 0b00111110, 0b01111100, 0b00000000
};
const unsigned char PROGMEM petHot[] = {
  0b00000000, 0b00000000, 0b00000000, 0b00000000,
  0b00000000, 0b11100000, 0b00000111, 0b00000000,
  0b00000001, 0b00010000, 0b00001000, 0b10000000,
  0b00000010, 0b00010000, 0b00001000, 0b01000000,
  0b00000100, 0b11001000, 0b00010011, 0b00100000,
  0b00000100, 0b11001000, 0b00010011, 0b00100000,
  0b00000100, 0b11100100, 0b00100111, 0b00100000,
  0b00000010, 0b01110010, 0b01001110, 0b01000000,
  0b00000001, 0b01111010, 0b01011110, 0b10001100,
  0b00000001, 0b00011001, 0b10011000, 0b10000011,
  0b00000010, 0b00000000, 0b00000000, 0b01000000,
  0b00000100, 0b00000000, 0b00000000, 0b00100000,
  0b00000100, 0b00000000, 0b00000000, 0b00100000,
  0b00000100, 0b00011000, 0b00011000, 0b00100000,
  0b00001000, 0b00100100, 0b00100100, 0b00010000,
  0b00001000, 0b00100100, 0b00100100, 0b00010000,
  0b00001000, 0b00011001, 0b10011000, 0b00010000,
  0b00001001, 0b01000000, 0b00000000, 0b00010000,
  0b00001000, 0b10000000, 0b00000000, 0b00010000,
  0b00001000, 0b00001111, 0b11110010, 0b10010000,
  0b00000100, 0b00000010, 0b01000001, 0b00100000,
  0b00000100, 0b00000011, 0b11000000, 0b00100000,
  0b00000011, 0b00000000, 0b00000000, 0b11000000,
  0b00000010, 0b00000000, 0b00000000, 0b01000000,
  0b00000100, 0b00000000, 0b00000000, 0b00100000,
  0b11000100, 0b01000000, 0b00000010, 0b00100000,
  0b00110010, 0b01001010, 0b00000010, 0b01000000,
  0b00000001, 0b11000100, 0b00000011, 0b10000000,
  0b00000000, 0b01000000, 0b00000010, 0b00000000,
  0b00000000, 0b01000000, 0b00000010, 0b00000000,
  0b00000000, 0b01000001, 0b10000010, 0b00000000,
  0b00000000, 0b00111110, 0b01111100, 0b00000000
};
const unsigned char PROGMEM petTired[] = {
  0b00000000, 0b00000000, 0b00000000, 0b00000000,
  0b00000111, 0b10000000, 0b00000001, 0b11100000,
  0b00011100, 0b11000000, 0b00000011, 0b00111000,
  0b00010000, 0b00110000, 0b00001100, 0b00001000,
  0b00110011, 0b00001000, 0b00010000, 0b11001100,
  0b00100111, 0b11000100, 0b00100011, 0b11100100,
  0b00100011, 0b11100100, 0b00100111, 0b11000100,
  0b00011000, 0b11110110, 0b01101111, 0b00011000,
  0b00001100, 0b00110011, 0b11001100, 0b00110000,
  0b00000111, 0b00000000, 0b00000000, 0b11000000,
  0b00000001, 0b00000000, 0b00000000, 0b10000000,
  0b00000111, 0b00000000, 0b00000000, 0b11100000,
  0b00000100, 0b00000000, 0b00000000, 0b00100000,
  0b00000100, 0b00000000, 0b00000000, 0b00100000,
  0b00001000, 0b00111100, 0b00111100, 0b00010000,
  0b00001000, 0b00001100, 0b00001100, 0b00010000,
  0b00001000, 0b00000001, 0b10000000, 0b00010000,
  0b00001001, 0b01000000, 0b00000000, 0b00010000,
  0b00001000, 0b10000000, 0b00000000, 0b00010000,
  0b00001000, 0b00001111, 0b11110000, 0b00010000,
  0b00000100, 0b00000010, 0b01000000, 0b00100000,
  0b00000100, 0b00000011, 0b11000000, 0b00100000,
  0b00000011, 0b00000000, 0b00000000, 0b11000000,
  0b00000010, 0b00000000, 0b00000000, 0b01000000,
  0b00000100, 0b00000000, 0b00000000, 0b00100000,
  0b00000100, 0b00000000, 0b00000000, 0b00100000,
  0b00000010, 0b01000000, 0b00000010, 0b01000000,
  0b00000001, 0b11000000, 0b00000011, 0b10000000,
  0b00000000, 0b01000000, 0b00000010, 0b00000000,
  0b00000000, 0b01000000, 0b00000010, 0b00000000,
  0b00000000, 0b01000001, 0b10000010, 0b00000000,
  0b00000000, 0b00111110, 0b01111100, 0b00000000
};
const unsigned char PROGMEM petHungry[] = {
  0b00000000, 0b00000000, 0b00000000, 0b00000000,
  0b00000111, 0b10000000, 0b00000001, 0b11100000,
  0b00011100, 0b11000000, 0b00000011, 0b00111000,
  0b00010000, 0b00110000, 0b00001100, 0b00001000,
  0b00110011, 0b00001000, 0b00010000, 0b11001100,
  0b00100111, 0b11000100, 0b00100011, 0b11100100,
  0b00100011, 0b11100100, 0b00100111, 0b11000100,
  0b00011000, 0b11110110, 0b01101111, 0b00011000,
  0b00001100, 0b00110011, 0b11001100, 0b00110000,
  0b00000111, 0b00000000, 0b00000000, 0b11000000,
  0b00000001, 0b00000000, 0b00000000, 0b10000000,
  0b00000111, 0b00000000, 0b00000000, 0b11100000,
  0b00000100, 0b00000000, 0b00000000, 0b00100000,
  0b00000100, 0b00011000, 0b00011000, 0b00100000,
  0b00001000, 0b00011000, 0b00011000, 0b00010000,
  0b00001000, 0b00011000, 0b00011000, 0b00010000,
  0b00001000, 0b00000001, 0b10000000, 0b00010000,
  0b00001000, 0b00000000, 0b00000000, 0b00010000,
  0b00001000, 0b00000000, 0b00000000, 0b00010000,
  0b00001000, 0b00001111, 0b11110000, 0b00010000,
  0b00000100, 0b00010010, 0b01001000, 0b00100000,
  0b00000100, 0b00000011, 0b11000000, 0b00100000,
  0b00000011, 0b00000000, 0b00000000, 0b11000000,
  0b00000010, 0b00000000, 0b00000000, 0b01000000,
  0b00000100, 0b00000000, 0b00000000, 0b00100000,
  0b00000100, 0b00000000, 0b00000000, 0b00100000,
  0b00000010, 0b01000000, 0b00000010, 0b01000000,
  0b00000001, 0b11000000, 0b00000011, 0b10000000,
  0b00000000, 0b01000000, 0b00000010, 0b00000000,
  0b00000000, 0b01000000, 0b00000010, 0b00000000,
  0b00000000, 0b01000001, 0b10000010, 0b00000000,
  0b00000000, 0b00111110, 0b01111100, 0b00000000
};
const unsigned char PROGMEM petDead[] = {
  0b00000000, 0b00000000, 0b00000000, 0b00000000,
  0b00000000, 0b11100000, 0b00000111, 0b00000000,
  0b00000001, 0b00010000, 0b00001000, 0b10000000,
  0b00000010, 0b00010000, 0b00001000, 0b01000000,
  0b00000100, 0b11001000, 0b00010011, 0b00100000,
  0b00000100, 0b11001000, 0b00010011, 0b00100000,
  0b00000100, 0b11100100, 0b00100111, 0b00100000,
  0b00000010, 0b01110010, 0b01001110, 0b01000000,
  0b00000001, 0b01111010, 0b01011110, 0b10000000,
  0b00000001, 0b00011001, 0b10011000, 0b10000000,
  0b00000010, 0b00000000, 0b00000000, 0b01000000,
  0b00000100, 0b00000000, 0b00000000, 0b00100000,
  0b00000100, 0b00000000, 0b00000000, 0b00100000,
  0b00000100, 0b01000100, 0b00100010, 0b00100000,
  0b00001000, 0b00101000, 0b00010100, 0b00010000,
  0b00001000, 0b00010000, 0b00001000, 0b00010000,
  0b00001000, 0b00101001, 0b10010100, 0b00010000,
  0b00001000, 0b01000100, 0b00100010, 0b00010000,
  0b00001000, 0b00000000, 0b00000000, 0b00010000,
  0b00001000, 0b00001111, 0b11110000, 0b00010000,
  0b00000100, 0b00010010, 0b01001000, 0b00100000,
  0b00000100, 0b00000011, 0b11000000, 0b00100000,
  0b00000011, 0b00000000, 0b00000000, 0b11000000,
  0b00000010, 0b00000000, 0b00000000, 0b01000000,
  0b00000100, 0b00000000, 0b00000000, 0b00100000,
  0b00000100, 0b01000000, 0b00000010, 0b00100000,
  0b00000010, 0b01000000, 0b00000010, 0b01000000,
  0b00000001, 0b11000000, 0b00000011, 0b10000000,
  0b00000000, 0b01000000, 0b00000010, 0b00000000,
  0b00000000, 0b01000000, 0b00000010, 0b00000000,
  0b00000000, 0b01000001, 0b10000010, 0b00000000,
  0b00000000, 0b00111110, 0b01111100, 0b00000000
};
//WALK RIGHT
const unsigned char PROGMEM walkRightF1[] = {
  0b00000000, 0b00000000, 0b00000000, 0b00000000,
  0b00000000, 0b00011111, 0b00000000, 0b11100000,
  0b00000000, 0b00110001, 0b10000011, 0b00100000,
  0b00000000, 0b00100000, 0b10000100, 0b00010000,
  0b00000000, 0b01100110, 0b10001000, 0b11010000,
  0b00000000, 0b01001110, 0b10011001, 0b11010000,
  0b00000000, 0b11011100, 0b10010011, 0b10110000,
  0b00000000, 0b10011001, 0b00110011, 0b00100000,
  0b00000001, 0b10011001, 0b11100011, 0b01000000,
  0b00000001, 0b00000000, 0b00000000, 0b01000000,
  0b00000001, 0b00000000, 0b00000000, 0b10000000,
  0b00000111, 0b00000000, 0b00000000, 0b11100000,
  0b00000100, 0b00000000, 0b00000000, 0b00100000,
  0b00000100, 0b00000110, 0b00001100, 0b00100000,
  0b00001000, 0b00000110, 0b00001100, 0b00010000,
  0b00001000, 0b00000110, 0b00001100, 0b00010000,
  0b00001000, 0b00000000, 0b01100000, 0b00010000,
  0b00001000, 0b00000000, 0b00000000, 0b00010000,
  0b00001000, 0b00000000, 0b00000000, 0b00010000,
  0b00001000, 0b00000001, 0b11111100, 0b00010000,
  0b00000100, 0b00000000, 0b01001000, 0b00100000,
  0b00000100, 0b00000000, 0b01111000, 0b00100000,
  0b00000011, 0b00000000, 0b00000000, 0b11000000,
  0b00000010, 0b00000000, 0b00000000, 0b01000000,
  0b00000100, 0b00000000, 0b00000000, 0b00100000,
  0b00000100, 0b00100000, 0b00000001, 0b00100000,
  0b00000010, 0b00100000, 0b00000001, 0b01000000,
  0b00000001, 0b11000000, 0b00000001, 0b10000000,
  0b00000000, 0b01000000, 0b00000001, 0b00000000,
  0b00000000, 0b01000001, 0b11000001, 0b00000000,
  0b00000000, 0b01000001, 0b00111110, 0b00000000,
  0b00000000, 0b00111111, 0b00000000, 0b00000000
};
const unsigned char PROGMEM walkRightF2[] = {
  0b00000000, 0b00011110, 0b00000011, 0b11000000,
  0b00000000, 0b00100001, 0b00000100, 0b00100000,
  0b00000000, 0b01001101, 0b00001001, 0b10100000,
  0b00000000, 0b01001101, 0b00001011, 0b10100000,
  0b00000000, 0b01011001, 0b00011011, 0b01000000,
  0b00000000, 0b10011011, 0b00010011, 0b01000000,
  0b00000000, 0b10011010, 0b00010111, 0b01000000,
  0b00000001, 0b10111010, 0b00110111, 0b01000000,
  0b00000001, 0b00111011, 0b11100110, 0b01000000,
  0b00000001, 0b00000000, 0b00000000, 0b11000000,
  0b00000001, 0b00000000, 0b00000000, 0b10000000,
  0b00000111, 0b00000000, 0b00000000, 0b11100000,
  0b00000100, 0b00000000, 0b00000000, 0b00100000,
  0b00000100, 0b00000110, 0b00001100, 0b00100000,
  0b00001000, 0b00000110, 0b00001100, 0b00010000,
  0b00001000, 0b00000110, 0b00001100, 0b00010000,
  0b00001000, 0b00000000, 0b01100000, 0b00010000,
  0b00001000, 0b00000000, 0b00000000, 0b00010000,
  0b00001000, 0b00000000, 0b00000000, 0b00010000,
  0b00001000, 0b00000001, 0b11111100, 0b00010000,
  0b00000100, 0b00000000, 0b01001000, 0b00100000,
  0b00000100, 0b00000000, 0b01111000, 0b00100000,
  0b00000011, 0b00000000, 0b00000000, 0b11000000,
  0b00000010, 0b00000000, 0b00000000, 0b01000000,
  0b00000100, 0b00000000, 0b00000000, 0b00100000,
  0b00000100, 0b00100000, 0b00000001, 0b00100000,
  0b00000010, 0b00100000, 0b00000001, 0b01000000,
  0b00000001, 0b11000000, 0b00000001, 0b10000000,
  0b00000000, 0b01000000, 0b00000001, 0b00000000,
  0b00000000, 0b01000001, 0b11100001, 0b00000000,
  0b00000000, 0b00111110, 0b00100001, 0b00000000,
  0b00000000, 0b00000000, 0b00011110, 0b00000000
};
//WALK LEFT
const unsigned char PROGMEM walkLeftF1[] = {
  0b00000000, 0b00000000, 0b00000000, 0b00000000,
  0b00000111, 0b00000000, 0b11111000, 0b00000000,
  0b00000100, 0b11000001, 0b10001100, 0b00000000,
  0b00001000, 0b00100001, 0b00000100, 0b00000000,
  0b00001011, 0b00010001, 0b01100110, 0b00000000,
  0b00001011, 0b10011001, 0b01110010, 0b00000000,
  0b00001101, 0b11001001, 0b00111011, 0b00000000,
  0b00000100, 0b11001100, 0b10011001, 0b00000000,
  0b00000010, 0b11000111, 0b10011001, 0b10000000,
  0b00000010, 0b00000000, 0b00000000, 0b10000000,
  0b00000001, 0b00000000, 0b00000000, 0b10000000,
  0b00000111, 0b00000000, 0b00000000, 0b11100000,
  0b00000100, 0b00000000, 0b00000000, 0b00100000,
  0b00000100, 0b00110000, 0b01100000, 0b00100000,
  0b00001000, 0b00110000, 0b01100000, 0b00010000,
  0b00001000, 0b00110000, 0b01100000, 0b00010000,
  0b00001000, 0b00000110, 0b00000000, 0b00010000,
  0b00001000, 0b00000000, 0b00000000, 0b00010000,
  0b00001000, 0b00000000, 0b00000000, 0b00010000,
  0b00001000, 0b00111111, 0b10000000, 0b00010000,
  0b00000100, 0b00010010, 0b00000000, 0b00100000,
  0b00000100, 0b00011110, 0b00000000, 0b00100000,
  0b00000011, 0b00000000, 0b00000000, 0b11000000,
  0b00000010, 0b00000000, 0b00000000, 0b01000000,
  0b00000100, 0b00000000, 0b00000000, 0b00100000,
  0b00000100, 0b10000000, 0b00000100, 0b00100000,
  0b00000010, 0b10000000, 0b00000100, 0b01000000,
  0b00000001, 0b10000000, 0b00000011, 0b10000000,
  0b00000000, 0b10000000, 0b00000010, 0b00000000,
  0b00000000, 0b10000011, 0b10000010, 0b00000000,
  0b00000000, 0b01111100, 0b10000010, 0b00000000,
  0b00000000, 0b00000000, 0b11111100, 0b00000000
};
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
void loop(){
  xValue = analogRead(X_PIN) - xCenter;
  yValue = analogRead(Y_PIN) - yCenter;

  if (abs(xValue) > deadzone || abs(yValue) > deadzone){
    joystickMoving = true;
  }else{
    joystickMoving = false;
  }

  if (millis() - lastTempRequest >= tempInterval){
    sensors.requestTemperatures();
    currentTemp = sensors.getTempCByIndex(0);
    lastTempRequest = millis();
  }

  checkButtons();
  updatePet();
  handleScreenLogic();

  if (joystickMoving && !tttPlaying){
    lastInteractionTime = millis();

    if (abs(xValue) > abs(yValue)){
      if (xValue > 0) changeState(WALK_RIGHT);
      else changeState(WALK_LEFT);
    }else{
      if (yValue > 0) changeState(WALK_AWAY);
      else changeState(WALK_TOWARDS);
    }

    if (!itemSpawned && (millis() - lastSpawnCheck >= spawnRollInterval)){
      lastSpawnCheck = millis();
      if (random(0, 100) < 5){
        itemSpawned = true;
        spawnedItemType = random(0, 2);
        tone(BUZZER_PIN, 1500, 80); 
      }
    }
  }else{
    if (currentScreen == SCREEN_MAIN && !actionActive){
      changeState(WALK_TOWARDS); 
    }
  }

  render();
  delay(30);
}

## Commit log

2026-06-16 Rename tamagotchi 2-B_Cu.gbr to leebyte-B_Cu.gbr
    [leebyte-B_Cu.gbr]
2026-06-16 Rename tamagotchi 2-B_Mask.gbr to leebyte-B_Mask.gbr
    [leebyte-B_Mask.gbr]
2026-06-16 Rename tamagotchi 2-B_Paste.gbr to leebyte-B_Paste.gbr
    [leebyte-B_Paste.gbr]
2026-06-16 Rename tamagotchi 2-B_Silkscreen.gbr to leebyte-B_Silkscreen.gbr
    [leebyte-B_Silkscreen.gbr]
2026-06-16 Rename tamagotchi 2-Edge_Cuts.gbr to leebyte-Edge_Cuts.gbr
    [leebyte-Edge_Cuts.gbr]
2026-06-16 Rename tamagotchi 2-F_Cu.gbr to leebyte-F_Cu.gbr
    [leebyte-F_Cu.gbr]
2026-06-16 Rename tamagotchi 2-F_Mask.gbr to leebyte-F_Mask.gbr
    [leebyte-F_Mask.gbr]
2026-06-16 Rename tamagotchi 2-F_Paste.gbr to leebyte-F_Paste.gbr
    [leebyte-F_Paste.gbr]
2026-06-16 Rename tamagotchi 2-F_Silkscreen.gbr to leebyte-F_Silkscreen.gbr
    [leebyte-F_Silkscreen.gbr]
2026-06-16 Rename tamagotchi 2-PTH.drl to leebyte-PTH.drl
    [leebyte-PTH.drl]
2026-06-16 Rename tamagotchi 2-job.gbrjob to leebyte-job.gbrjob
    [leebyte-job.gbrjob]
2026-06-16 Rename tamagotchi 2-NPTH.drl to leebyte-NPTH.drl
    [leebyte-NPTH.drl]
2026-06-16 Rename tamagotchi 2.kicad_pcb to leebyte.kicad_pcb
    [leebyte.kicad_pcb]
2026-06-16 Rename tamagotchi 2.kicad_pro to leebyte.kicad_pro
2026-06-16 Rename tamagotchi 2.kicad_sch to leebyte.kicad_sch
    [leebyte.kicad_sch]
2026-06-16 Create gerbers
2026-06-16 Rename Áã¼þ11 (1).step to DS18B20 model.step
    [DS18B20 model.step]
2026-06-16 Rename BUZ-TH_BD12.5-H7.0-P6.5 (1).step to Buzzer model.step
    [Buzzer model.step]
2026-06-16 Rename OLED-TH_L27.8-W27.2-P2.54_C9900033791 (1).step to 128x64 OLED model.step
    [128x64 OLED model.step]
2026-06-16 Rename RES-TH_D2.3-L6.5-P10.50 (1).step to 4.7k res model.step
    [4.7k res model.step]
2026-06-16 Rename SW-TH_4P-L4.5-W4.5-P3.00-LS4.8 (1).step to Tact Switch model.step
    [Tact Switch model.step]
2026-06-16 Rename Slide Switch.step to Slide Switch model.step
    [Slide Switch model.step]
2026-06-16 Rename tamagotchipcb123 1 - Hex socket head cap screw M3x0.50 x 8.step to M3x0.5mm 8mm Screw model.step
    [M3x0.5mm 8mm Screw model.step]
2026-06-16 Rename tamagotchipcb123 1 - PZ Pan head screw M1.6x0.35 x 8.step to M1.6x0.35mm 6mm Screw model.step
    [M1.6x0.35mm 6mm Screw model.step]
2026-06-16 Rename case/CAD/128x64 OLED model.step to case/CAD/128x64 OLED Model/model
2026-06-16 Rename case/CAD/4.7k res model.step to case/CAD/4.7k Resistor Model/model
2026-06-16 Rename case/CAD/Buzzer model.step to case/CAD/Buzzer Model/model
2026-06-16 Rename case/CAD/DS18B20 model.step to case/CAD/DS18B20 Model/mode
2026-06-16 Rename case/CAD/M1.6x0.35mm 6mm Screw model.step to case/CAD/M1.6x0.35mm 6mm Screw Model/mod
2026-06-16 Rename case/CAD/M3x0.5mm 8mm Screw model.step to case/CAD/M3x0.5mm 8mm Screw Model/m
2026-06-16 Rename case/CAD/Slide Switch model.step to case/CAD/Slide Switch Model/m
2026-06-16 Rename case/CAD/Standoff m-f - M2 x 5 across flats 4mm (3).step to case/CAD/M2 4mm Standoff Model/m
2026-06-16 Rename Tact Switch model.step to Tact Switch Model
2026-06-16 Create Tact Switch Model
2026-06-16 Rename Hex nut style 1 grade A & B M2x0.4.step to Hex nut style 1 grade A & B M2x0.4.step
    [Hex nut style 1 grade A & B M2x0.4.step]
2026-06-16 Rename Hex nut style 1 grade A & B M2x0.4.stl to Hex nut style 1 grade A & B M2x0.4.stl
    [Hex nut style 1 grade A & B M2x0.4.stl]
